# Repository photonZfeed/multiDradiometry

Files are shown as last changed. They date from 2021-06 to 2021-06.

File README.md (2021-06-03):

# multiDradiometry

A device for a multi-dimensional resolving radiometric scanning method.

## Documentaition

The assembly of the device is documented in the [CAD section](./CAD/).

See also the [3D-pdf](./DOCUMENTATION/ND-Radiometry-Scanner/ND-Radiometry-Scanner.pdf) of the complete assembly.

The Python modules are documented in the [Python section](./Python/). See also the fairly detailed docstrings in the code.

## More information
Cite this repository: 

Links to the pulblicatons will be added when available.

## Licensing

<p >
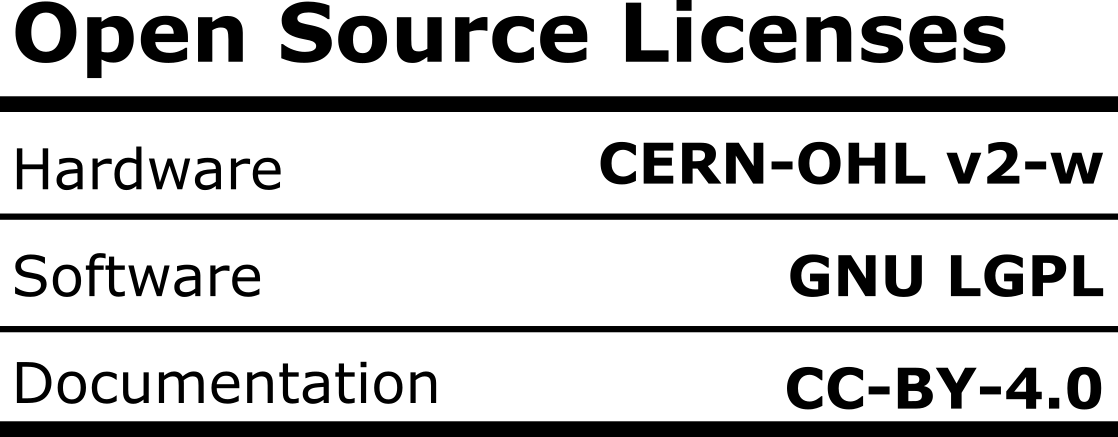
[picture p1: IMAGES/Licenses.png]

</p>

This project is open source. The software is released under the **GNU Lesser General Public Licence** (GNU LGPL). The hardware is released under the **CERN Open Hardware Licence Version 2 - Weakly Reciprocal Licence**.

**Please find the licenses [here](./License.md)**

### Package Licences

multiDradiometry links to or uses the following software, third-party libraries or hardware:

- [itom](https://itom.bitbucket.io/) in version 3.0 under GNU LGPL and ITO LGPL Exception version 1.0.
- [Python](https://python.org) 3 under PYTHON SOFTWARE FOUNDATION (PSF) LICENSE VERSION 2.
- Python-package [NumPy](numpy.org) under BSD compatible license.
- Python-package [feather-format](https://github.com/wesm/feather) under the Apache License, Version 2.0.
- Python-package [pyarrow](https://github.com/apache/arrow/tree/master/python) under the Apache License, Version 2.0.
- Python-package [pandas](https://pandas.pydata.org/) under BSD 3-Clause License.
- Python-package [tinkerforge](https://www.tinkerforge.com/en/doc/Software/API_Bindings_Python.html) under CC0 1.0 Universal License.
- Python-package [matplotlib](https://matplotlib.org) under PSF based, BSD compatible license.
- Python-package [KoradSerial](https://gist.github.com/k-nowicki/5379272) under MIT License.
- Python-package [colour_system](https://scipython.com/blog/converting-a-spectrum-to-a-colour/) by Christian Hill.
- Python-package [yagmail](https://github.com/kootenpv/yagmail) under MIT License.
- Python-package [scipy](https://scipy.org) under PSF based, BSD compatible license.
- Python-package [lmfit](https://lmfit.github.io/lmfit-py/index.html) under BSD-3 License.
- Python-package [sympy](https://github.com/sympy/sympy) under PSF based, BSD compatible License.
- Hardware: [OpenBuilds](https://openbuilds.com/), LLC design work under the CC BY-SA 4.0 License.
- Hardware: [Tinkerforge](https://www.tinkerforge.com) GmbH design work under the CERN Open Hardware License.

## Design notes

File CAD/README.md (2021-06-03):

# Mechanical Setup
The mechanical setup of the scanning device was built to move the spectrometer in x- and y-direction and the light source in z-direction. The scaffold hosting all other mechanical parts is set up with OpenBuilds linear aluminium rails with a length of 1 m. The main scaffold is built up from 12 main beams, namely 4 for every axis. In the following picture, these beams are labelled as main x-beam, main y-beam and main z-beam. Further on, the setup can be subdivided in 4 module types, each presenting one or more corners of the cubic device. To give a general overview, these modules are shown in following pictures as CAD-drawing as they are assembled in the actual device. Assigned colours do not always correspond to real colours but were chosen as visual aid. In addition, parts of the aluminium rails between the modules are cut out. The mechanical structure is self designed, the following parts or assemblies are customly designed, 3D-printed and displayed in dark grey in CAD-figures. They can be found [here](./ND-Radiometry-Scanner).

The modules are named after their position in the coordinate system being scanned by the device. Following this rule, the module which is closest to the origin of the coordinate system is called 000-module.  The individual modules are described in more detail and figure exerts below. 

See also the [3D-pdf](./DOCUMENTATION/ND-Radiometry-Scanner/ND-Radiometry-Scanner.pdf) of the complete assembly.

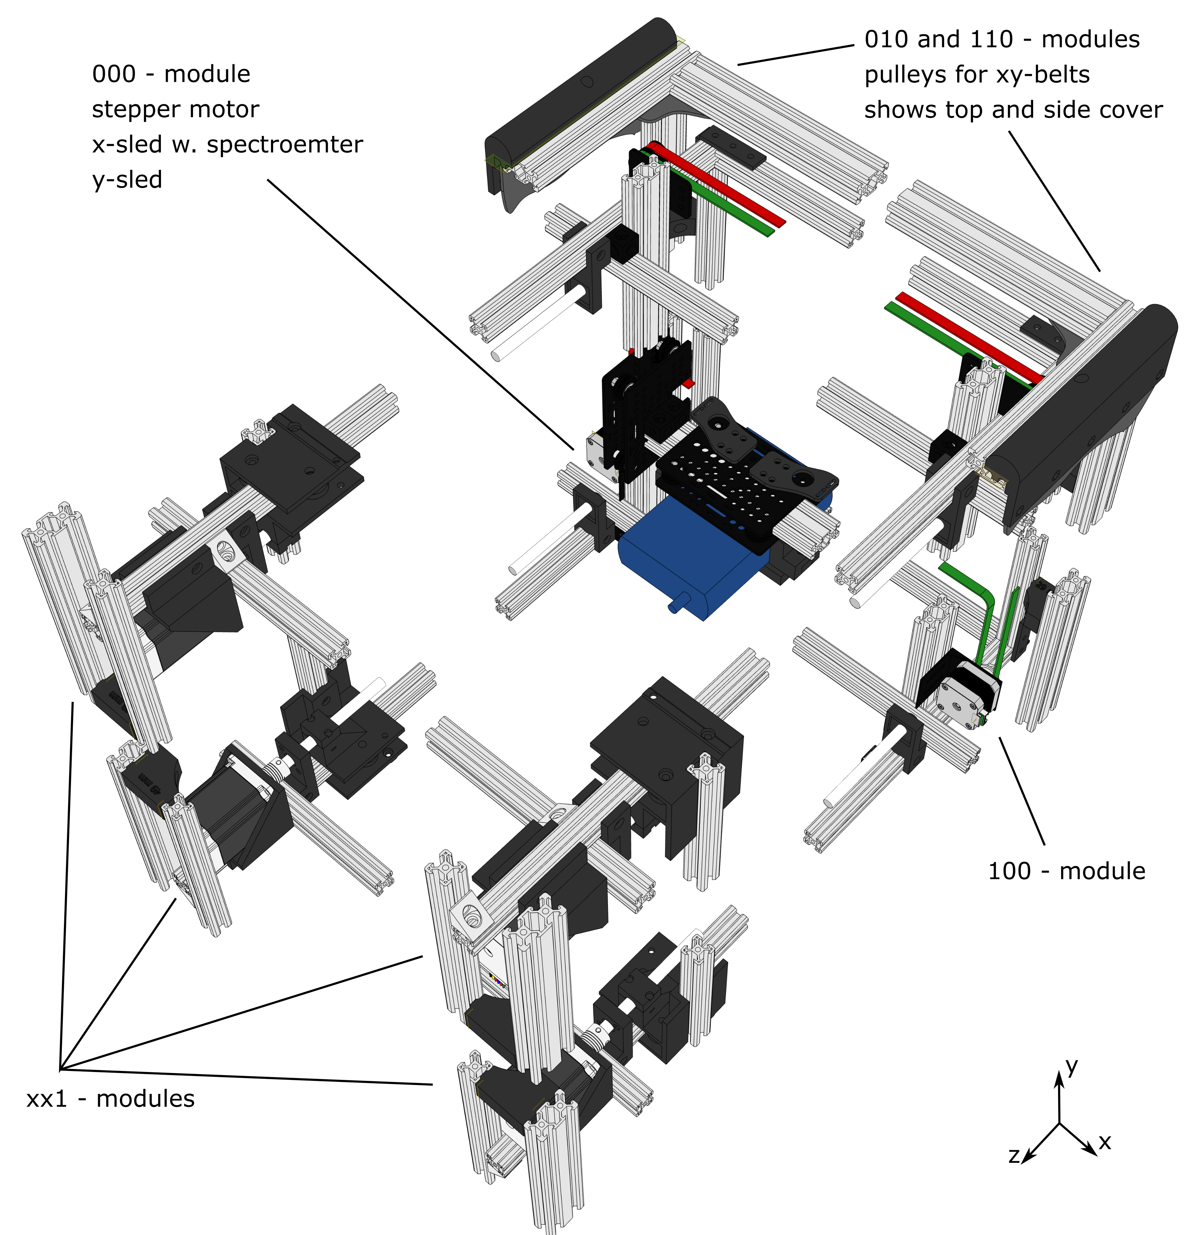
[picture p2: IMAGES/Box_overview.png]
General overview with all building block corners of the scanning device.


### 000-module

The 000-module including the x/y-slid system moving the spectrometer. The Core-XY technique is used to move this slide system. One of two motors needed for this system is visible, connected to the red belt. The spectrometer is mounted on the slide moving in x-direction on an aluminium beam rail. This rail is held by the two slides moving in y-direction on two main y-beams as rails. The general equations describing the movement of the spectrometer in x- and y-directions are:



and



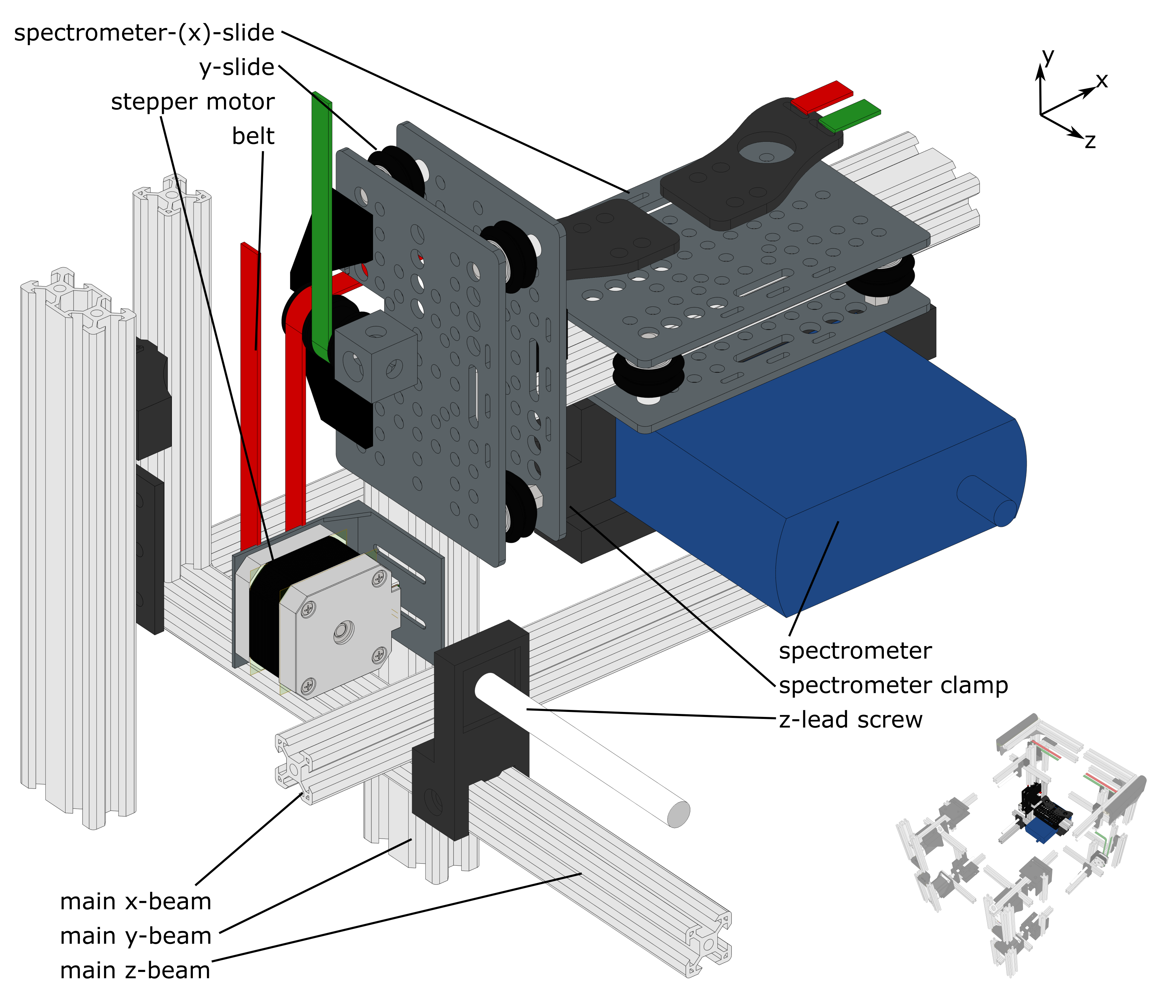
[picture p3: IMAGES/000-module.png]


### 100-module
The second motor moving the spectrometer is visible in the following figure, connected to the green belt. Here the y-slide is omitted for a better display of the main x, y and z-beam. The latter also hosts the z-lead screw, which is driving the z-slide. The belts for the x/y-slits are deflected by pulleys at the 010 and 110 position. 

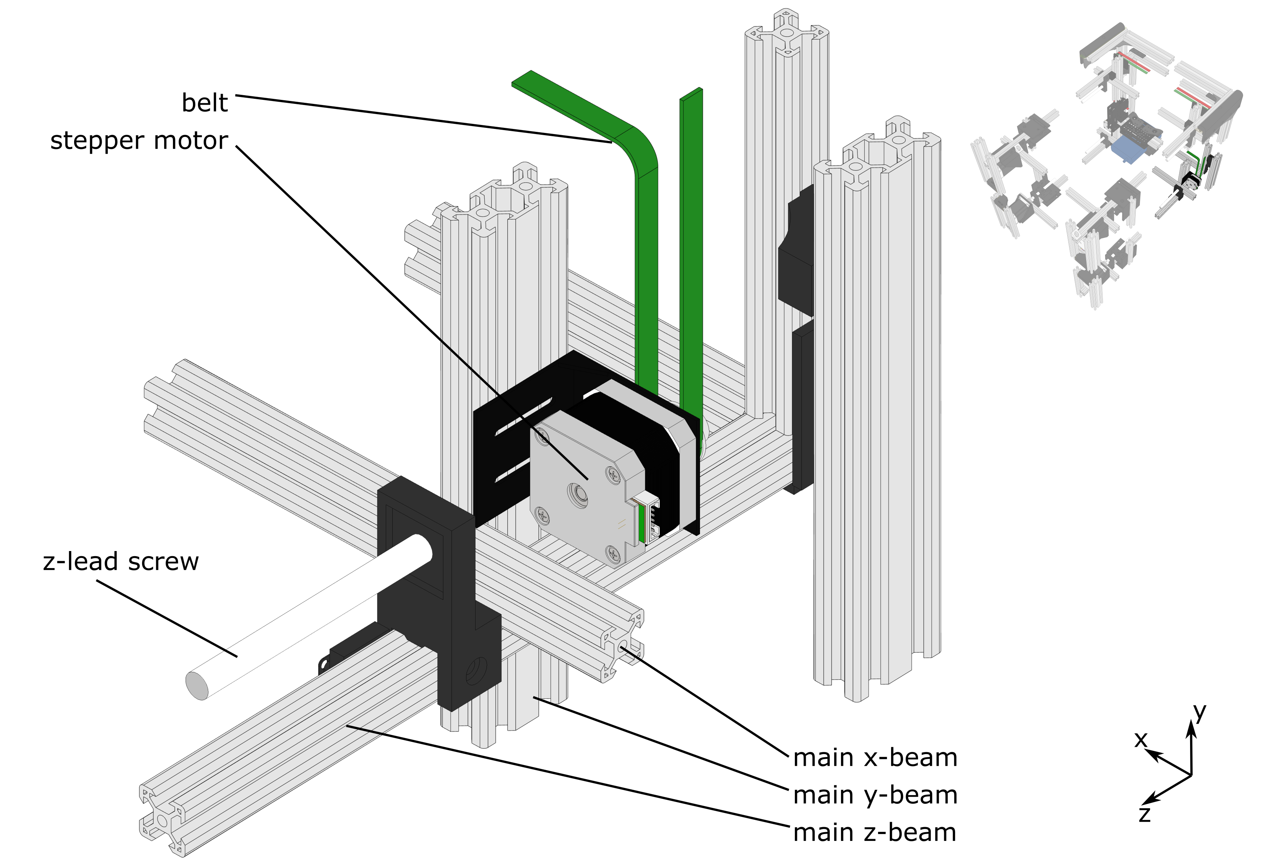
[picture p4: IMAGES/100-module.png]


### 010- and 101-module
To protect the scanning device from interfering light, the device can be covered with black polypropylene panels. The panel on the top side is mounted on a frame of aluminium beams and is screwed to the main scaffold. On this top cover frame, the side cover panels can be mounted by hanging them on the aluminium beams of the top cover. The hanging panels are then fixed at the cover gantry, which consists of aluminium rails connected with spacers to the main scaffold. The scaffold and spacers are shown in all CAD-figures, however, they are best visible in the following figure. This figure also shows one of 4 modules driving the z-slide assembly. This assembly consists of four slides running in all main z-beams as rails. The slides are all driven by a lead-screw and a stepper motor, moving only at the same time. The z-slides can be connected by aluminium beams to establish a moving scaffold for hosting the light source.

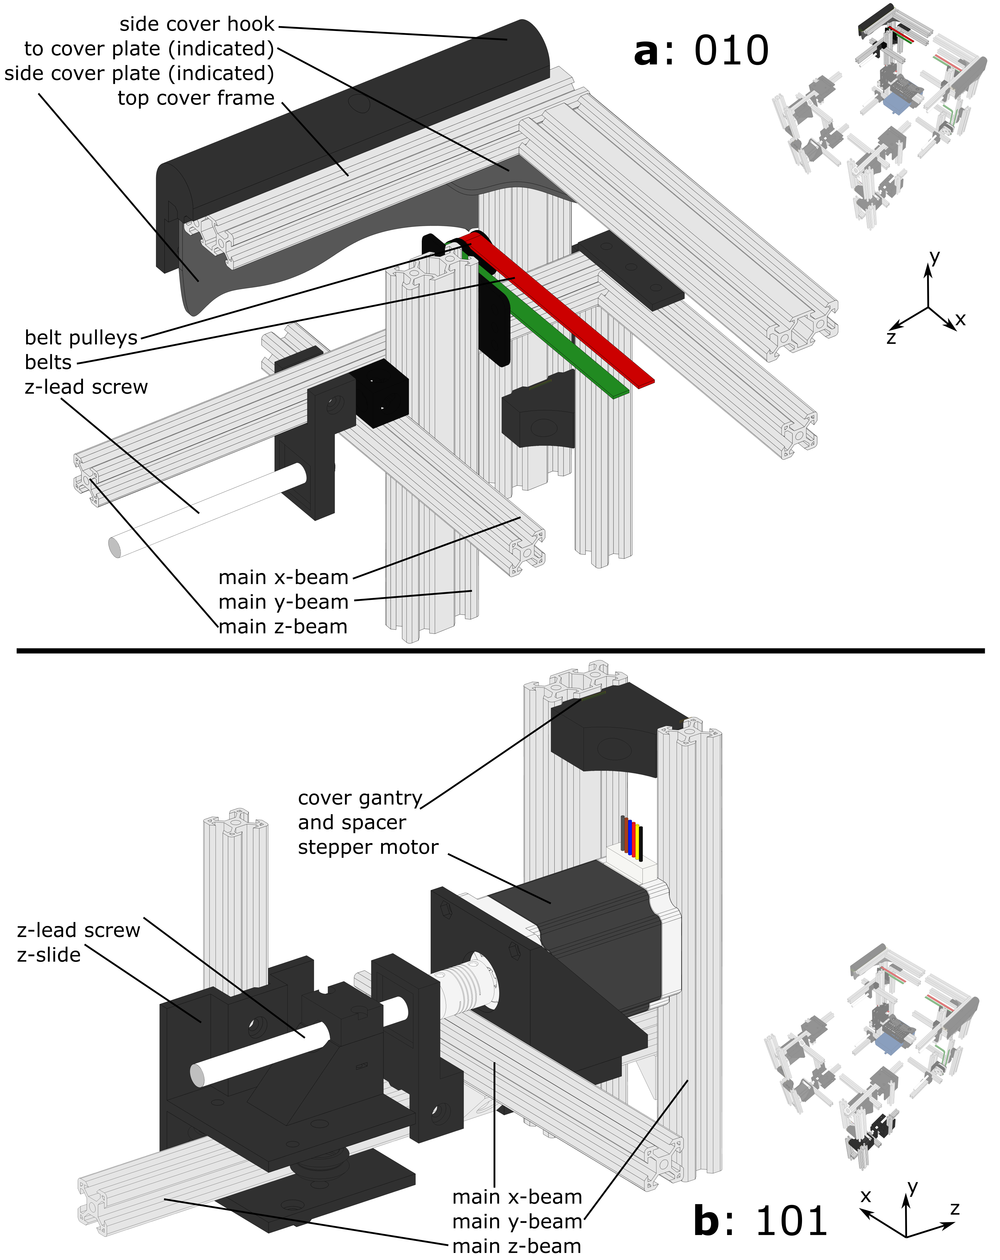
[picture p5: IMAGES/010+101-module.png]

## Tips to setup a new device

Start setting up the x/y frame and include the slides. Then you can install and test the electronixs for the x/y movement without too much space demands. Then yo can expand to the full frame and integrate the z-movement parts.

# Electric setup
The following figure shows a schematic setup of the used tinkerforge bricks to control the device. The master brick is connected to the PC running the controlling software. All bricks are stacked on top of each other, all bricklets are connected via cables. Each stepper brick is controlling one stepper motor for the x- and y-movement. Another stepper brick is controlling all stepper motors for the z-movement. One IO-16-bricklet is used to watch the end-stop triggers. A 24 V wall plug power supply is powering the stepper bricks as well as the cooling fan of the tinkerforge assembly. The used spectrometer and the power supply are connected directly to the PC via USB.
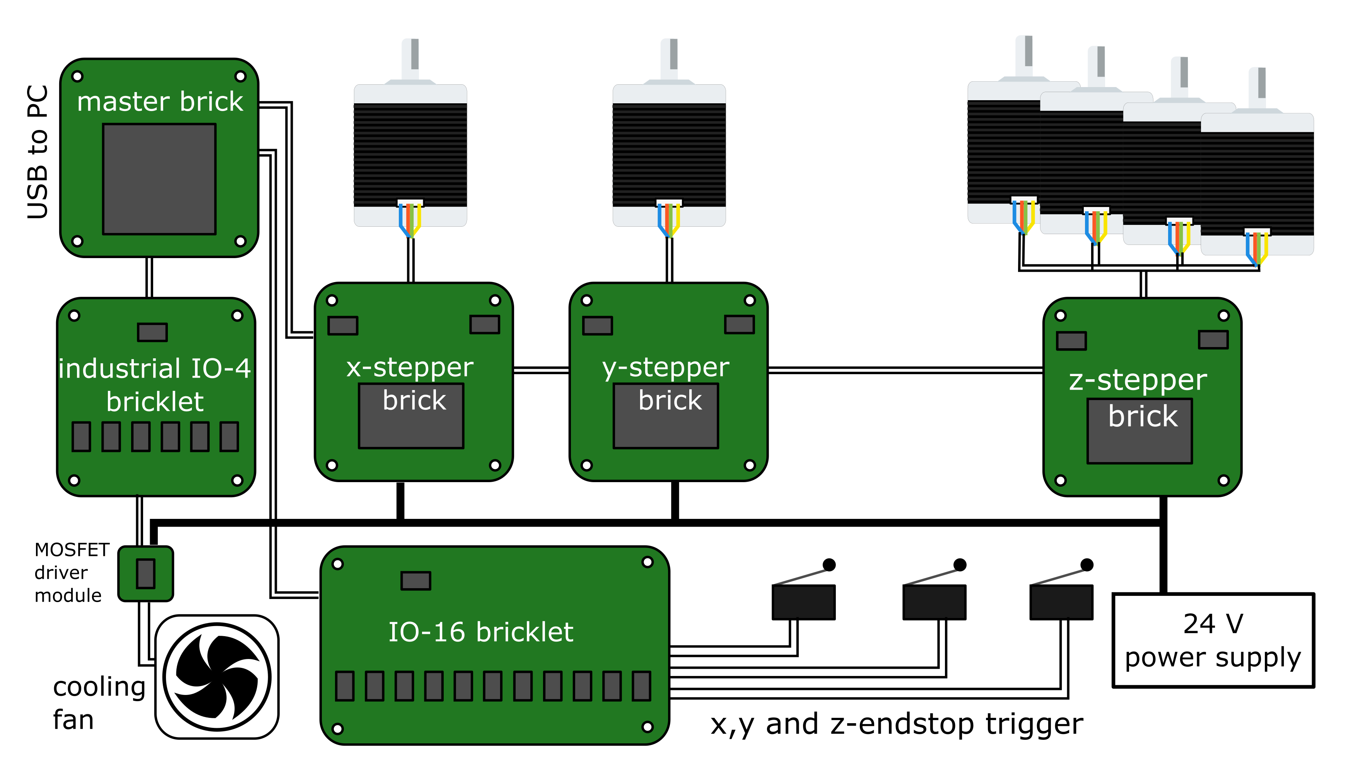
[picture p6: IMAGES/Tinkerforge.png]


# List of Parts

|  | Rails |
| --- | --- |
|12	|1000x20x20 V-slot rail|
|4	|860x20x20 V-slot rail|
|2	|913x20x20 V-slot rail|
|1	|975x20x20 V-slot rail|
|6	|1000x40x20 V-slot rail|
|2	|960x40x20 V-slot rail|
|1	|810.4x40x20 V-slot rail|

|	|OpenBulids Parts|
| --- | --- |
|2	 |idler pulley plate|
|2	 |NEMA 17 90deg mount plate|
|8	 |straight bracket|
|18	 |Three way cube|
|12	|6\,mm spacer|
|16	|asymmetric spacer|
|2	|Gantry Plate - universal|
|4	|Gantry Plate - universal (cut to fit belts)|
|8	|smooth idler pulley assembly|
|24	|V-Slot wheel assembly|

| | Screws and Nuts|
| --- | --- |
|32	|M3 nut|
|16	|M3 square nut|
|32	|M3x10 ISO 7380|
|8	|M3x25 ISO 7380|
|12	|M3x8 ISO 7380|
|16	|M4 nut|
|16	|M4x10|
|4	|M5 1mm spacer|
|82	|M5 nut|
|154	|M5 tee nut|
|165	|M5 washers|
|6	|M5x20 ISO 7380|
|16	|M5x35 ISO 7380|
|12	|M5x40 ISO 7380|
|8	|M5x60 ISO 4762|
|65	|M5x8 ISO 10642|
|137	|M5x8 ISO 7380|
	
| | Moving and Other|
| --- | --- |
|2	 |16 teeth HTD 3M  9mm belt pulley|
|8	 |19x10x5 ball bearing|
|4	 |6mm/10mm coupling|
|4	 |leadscrew Tr.10x3x1000|
|4	 |Tr.10 x 3 hex nut length15mm width17mm|
|5	|3x1000x1000 black PP |
|13|\m	HTD 3M  9mm belt|

| | Printed Parts|
| --- | --- |
|8	 |cover gantry spacer|
|4	 |leadscrew end holder|
|4	 |leadscrew support|
|1	 |spectrometer clamp |
|4	 |z-motor mount|
|4	 |z-slide|
|2	|belt attachment|
|3	|limit switch mount|
|2	|pulley support|
|8	|side cover kook|
	
| | Electronic Parts|
| --- | --- |
|2	 |NEMA 17 stepper motor|
|4	 |NEMA 23 motor|
|1	|24V power supply|
|6 m|	end switch cable|
|1	|Industrial IO-4 bricklet|
|1	|IO-16 bricklet|
|3	|limit switch|
|1	|master brick|
|1	|micro usb cable|
|1	|mosfet driver module|
|3	|stepper brick|
|15 m|	stepper motor cable|
|2	|tinker forge cable|

# Capillary Reactor Models

The CAD-models of the reactors used in the linked publication can be found [here](./Reactors/).

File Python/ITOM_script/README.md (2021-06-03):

# radiometric_measurement

---

The module` radiometric_measurement `contains the class `ScanSurface`, which can be run in an ITOM environment to perform measurements with a radiometric scanning device developed at the Institute of Chemical Engineering, Ulm University.
    
The class ScanSurface controlling the measurement device is connected to the spectrometer, the power supply and the tinkerforge bricks, which control the stepper motors and end-stop switches. Must be run in an ITOM python environment.

## Usage
The following cole block shows an example of a script initializing an instance of the class `ScanSurface` class and starting a measurement. This script must be executed in ITOM. In line 3, the class instance `sc` gets initialized with the parameters described in the following section. After connecting to the hardware in line 8, the measurement is started in line 10 after a waiting time to leave the lab (line 9).

	from Skripts.radiometric_measurement import ScanSurface
	import time
	
	sc = ScanSurface(reactor='example_name', comment='example_comment', measurements=5, power_supply=True, current=0.5,
	                 slicelist=[10.8, 11.19, 11.58, 11.97, 12.36], 
	                 int_time_list=[0.142, 0.152, 0.163, 0.174, 0.185]
	                 )  # initialize an instance of the ScanSurface class
	sc.connect()
	time.sleep(2)  # an apropirate time to leave the lab
	sc.start_measurement()  # start the measurement

### Attributes constructed by \_\_init\_\_:

**reactor** ***(str):*** The name of the experiment, will be used for output folder and files.

**comment** ***(str):*** A comment for additional information, written to the logfile.

**measurements** ***(int):*** The size of measurements of a quadratic canvas in x/y-direction. The points are evenly spaced by 3.9 mm. The maximum total size is 153 (59.67 cm).

**power\_supply** ***(bool):*** If `True`, the script controlls the power supply with the given parameters for voltage and current. If `False`, a dark spectrum for the chosen integration time must be provided in the format "dark_'integration time'\_av'averages'.csv", whereas 'integration time' and 'averages' must be replaced with the respective numbers. The provided python script *darkspec.py* can help with that.

**voltage** ***(number, optional, default = 5.0):*** The voltage set for the power supply in Volt.

**current** ***(number, optional, default = 0.7):*** The current set for the power supply in Ampere.

**slicelist** ***(list):*** Sets up a list for all z-positions, in cm, to be measured: `[pos1, pos2, pos3...]`.

**int\_time\_list** ***(list):*** Sets up a list of the integration time for all z-positions, in seconds: `[time1, time2, time3...]`. Must be of the same length as parameter slicelist.

**averages** ***(int, optional, default = 2):*** The number of spectrometer measurements which result in one averaged measurement sent to python. A new transfer curve is needed for different average settings.

**x_start** ***(number, optional, default = 0.0):*** The x-position of the first measured pixel in cm.

**y_start** ***(number, optional, default = 0.0):*** The y-position of the first measured pixel in cm.

**log\_output** ***(boolean, optional, defalut = True):*** Saves a logfile, this is mandatory for further evaluation.

**linspace** ***(tuple, optional, default = False):*** Sets up a slicelist in the manner of the numpy linspace function *(start, stop, num)*. Linspace definitions can't be defined together with a list definition (slicelist or int\_time\_list)!

**int\_time\_linspace** ***(tuple, optional, default = False):*** Sets up an integration time list in the manner of the numpy linspace function *(start, stop, num)*. Must be used together with parameter linspace.

**sendmail** ***(bool, default is False):*** If `True`, the script will send a status mail after the 50th measurement of a respective z-slice. Attributes should be changed in the code.

### Attributes for status and debugging:

**is\_homed** ***(bool):*** Indicates overall homing status.

**bool\_home\_x** ***(bool):*** Indicates x homing status.

**bool\_home\_y** ***(bool):*** Indicates y homing status.

**z\_is\_homed** ***(bool):*** Indicates z homing status.

**status** ***(str):*** Indicated status `'idle'`, `'measuring'` or `'homing'`.

**path** ***(str):*** The filepath for result export. Normally consisting of '02Results/' the time as "%y%m%d_%H%M%S" and the string of the attribute reactor.

#### Attributes for the status mail function:

If sendmail is `True`, the script will send a status mail after the 50th measurement of a respective z-slice. Attributes should be changed in the code ([line 346](./Skripts/radiometric_measurement.py#L347-348)):

**yag** = yagmail.SMTP('fill your email here', 'fill your password here or use the keychain functionality of yagmail')

**mailto** ***(str):*** The receivers e-mail address.

**mailsubj** ***(str):*** Automatically generated subject.

**mailcont** ***(str):*** Automatically generated content.

**approx\_string** ***(str):*** Automatically generated string of the approximate ending time of the scan.

#### Attributes for Tinkerforge and Steppermotor setup:

For setting up a new machine, or if tinkerforge hardware is replaced, the respetive UIDs must be typed in the code ([line 300](./Skripts/radiometric_measurement.py#L300-304)):
	
**UIDSTEP1** ***(str):*** UID of Stepper Brick 1
	
**UIDSTEP2** ***(str):*** UID of Stepper Brick 2 Since a core xy-setup is used, there is no such a x or y stepper.
	
**UIDSTEP3** ***(str):*** UID of Stepper Brick 3 (z-direction).
	
**UIDIO** ***(str):*** UID of IO-16 Bricklet.
	
**UIDIDO4** ***(str):*** UID of IO-4 Bricklet.

**Optional tinkerforge attributes:**

**HOST** ***(str):*** "localhost"
	
**PORT** ***(int):*** 4223
	
**max\_vel** ***(int):*** Velocity of stepper 1 and 2.
	
**ramping** ***(int):*** Ramping of stepper 1 und 2.
	
**z\_max\_vel** ***(int):*** Velocity of z-steppers.
	
**z\_ramping** ***(int):*** Ramping of z-steppers.

#### Methods:

Please refer to the detailed docstrings insde the module's [code](./Skripts/radiometric_measurement.py).

- connect()

- start\_measurement()

- disconnect()

##### Debugging methods for idle mode: 
(idle mode = connected and homed, no measurement running, `mode=='idle'`)

- get\_position()

- get\_z\_position()

- goto\_position(position)

- tune\_inttime()

- manual\_homing()

- reset\_queue()

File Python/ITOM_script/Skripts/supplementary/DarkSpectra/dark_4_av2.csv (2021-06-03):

3.990000000000000000e+03
6.418500000000000000e+03
4.458000000000000000e+03
5.919500000000000000e+03
4.909000000000000000e+03
6.655500000000000000e+03
6.343000000000000000e+03
4.787000000000000000e+03
3.453500000000000000e+03
6.850000000000000000e+03
4.748500000000000000e+03
4.992500000000000000e+03
3.585000000000000000e+03
3.245500000000000000e+03
6.811500000000000000e+03
3.690000000000000000e+03
3.497000000000000000e+03
4.898500000000000000e+03
6.650500000000000000e+03
4.362500000000000000e+03
4.449500000000000000e+03
6.489500000000000000e+03
5.195000000000000000e+03
4.325000000000000000e+03
4.003000000000000000e+03
3.364500000000000000e+03
3.430500000000000000e+03
5.001500000000000000e+03
6.186500000000000000e+03
4.387000000000000000e+03
6.308000000000000000e+03
5.852000000000000000e+03
2.372500000000000000e+03
2.795000000000000000e+03
4.074000000000000000e+03
3.335000000000000000e+03
3.668000000000000000e+03
7.014000000000000000e+03
5.184500000000000000e+03
2.922000000000000000e+03
4.767500000000000000e+03
5.801500000000000000e+03
2.923000000000000000e+03
3.774000000000000000e+03
3.041500000000000000e+03
4.266500000000000000e+03
3.547500000000000000e+03
3.729500000000000000e+03
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

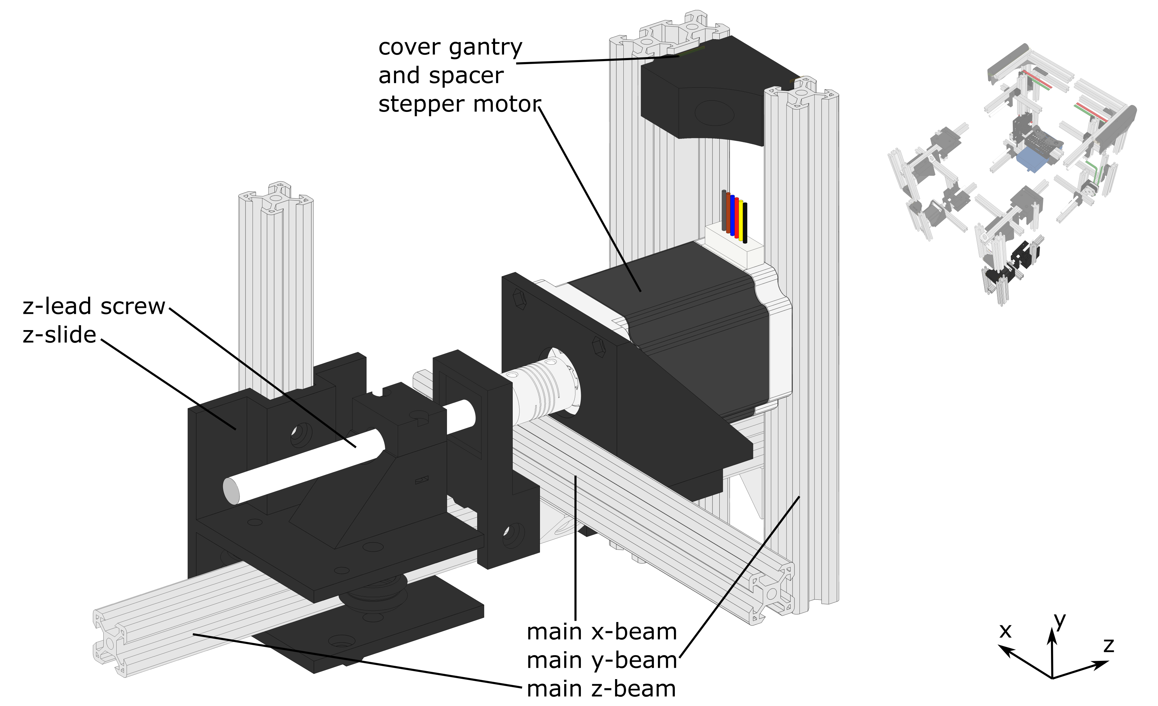
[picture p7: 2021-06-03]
IMAGES/101-module.png

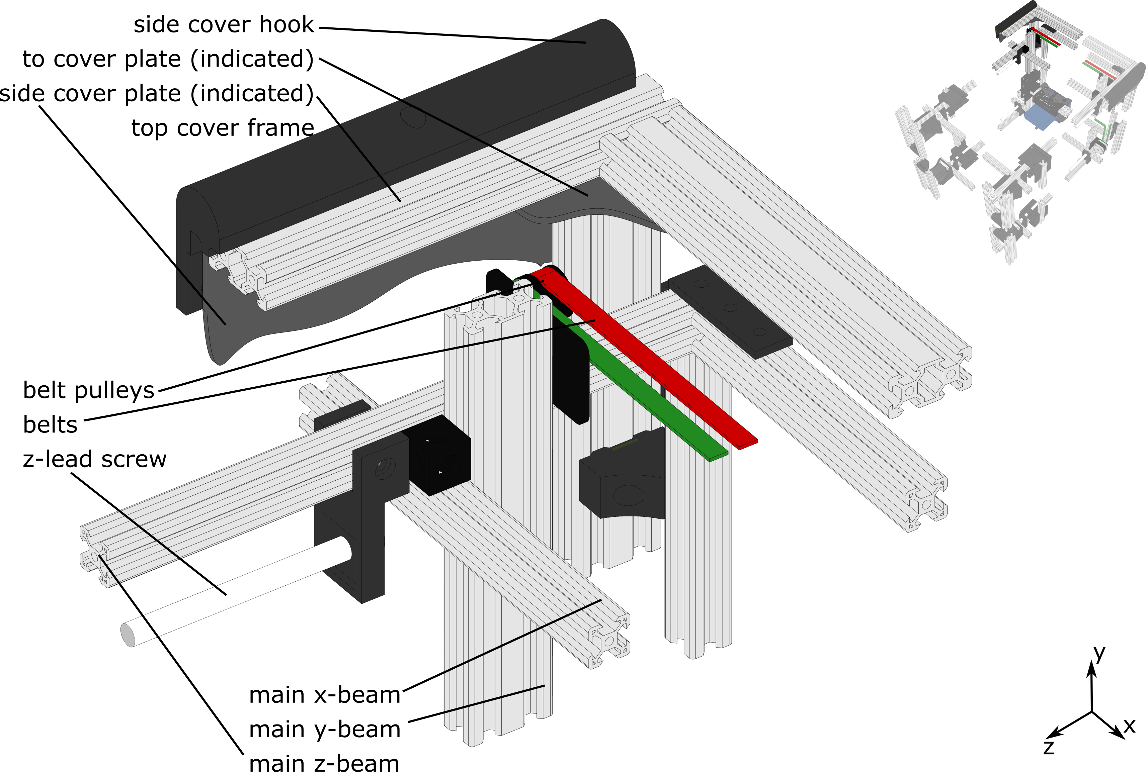
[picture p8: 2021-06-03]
IMAGES/010-module.png

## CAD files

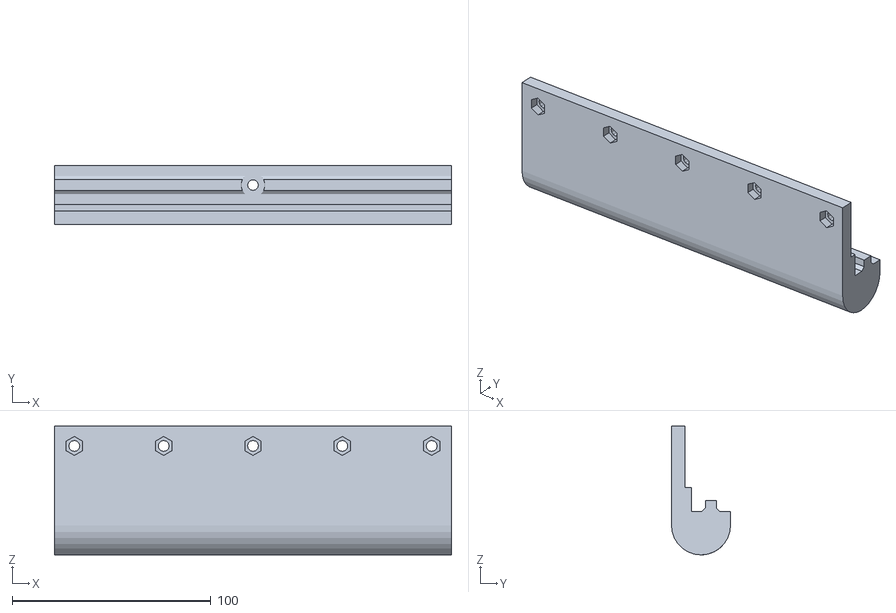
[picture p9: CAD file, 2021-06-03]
CAD/ND-Radiometry-Scanner/side_cover_hook.stl
200.0 x 29.8 x 64.9

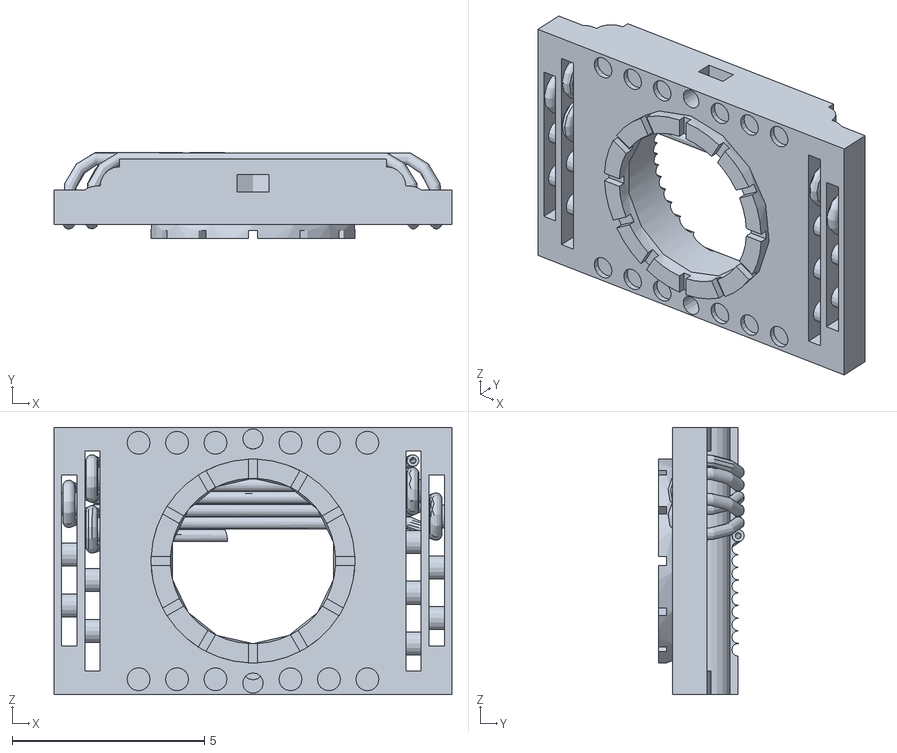
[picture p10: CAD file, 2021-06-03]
CAD/Reactors/SR_openend_with_caps.stl
10.4 x 2.22 x 6.95

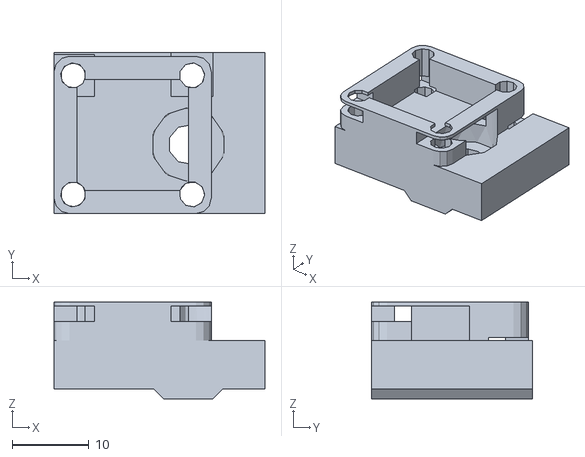
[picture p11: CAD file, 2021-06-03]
CAD/ND-Radiometry-Scanner/z_endstop_holder.stl
27.5 x 21.0 x 12.6

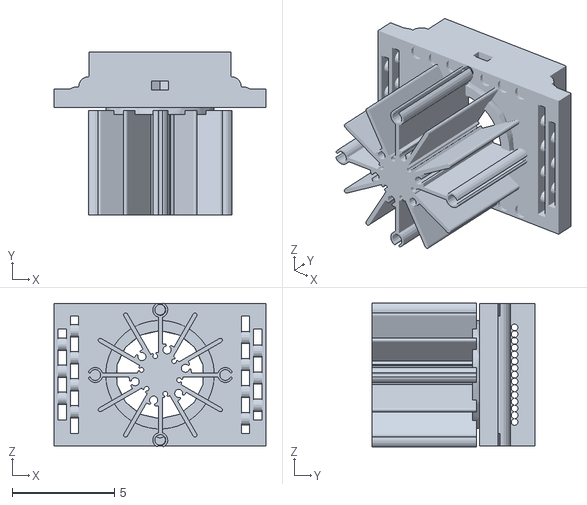
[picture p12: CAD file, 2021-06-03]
CAD/Reactors/SR.stl
10.4 x 7.97 x 7.01

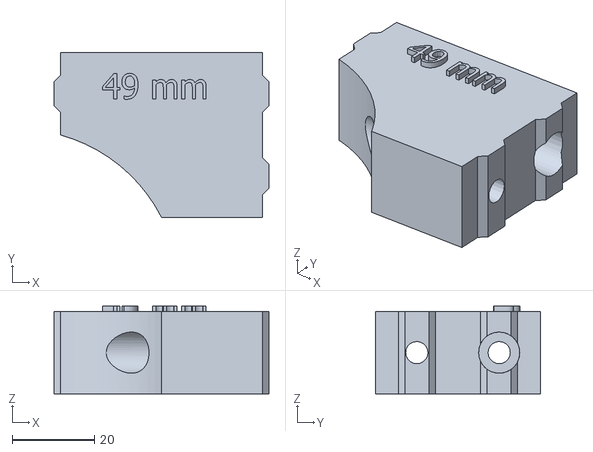
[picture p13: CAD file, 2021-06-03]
CAD/ND-Radiometry-Scanner/cover_gantry_spacer_4_9.stl
52.2 x 40.0 x 21.3

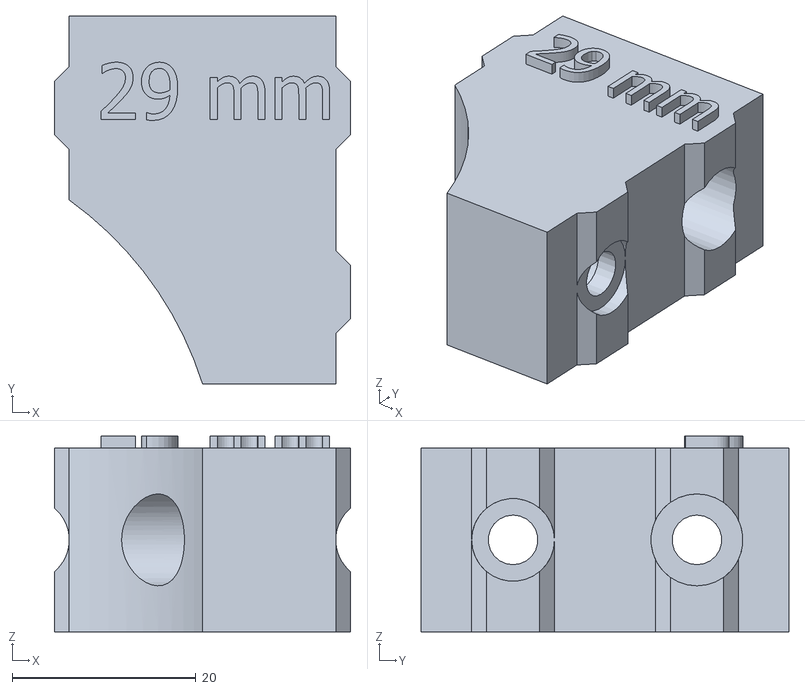
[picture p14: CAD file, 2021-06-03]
CAD/ND-Radiometry-Scanner/cover_gantry_spacer_2_9.stl
32.2 x 40.0 x 21.3

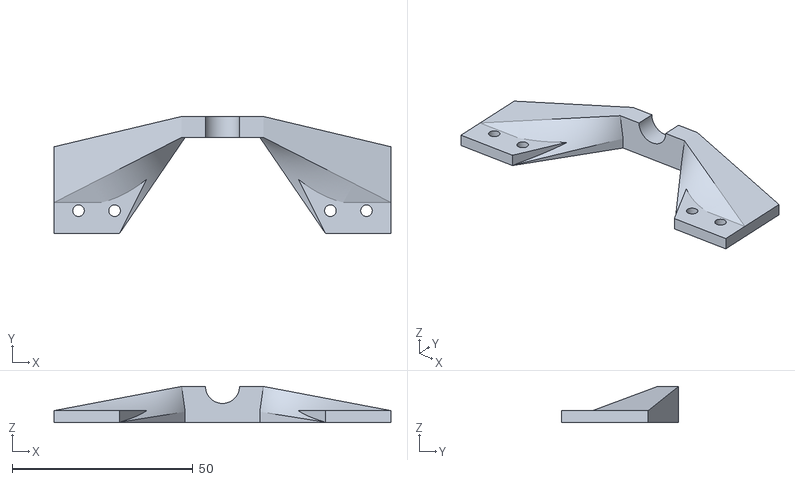
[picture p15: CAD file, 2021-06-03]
CAD/ND-Radiometry-Scanner/y_slide_pulley_support.stl
93.3 x 32.4 x 10.0

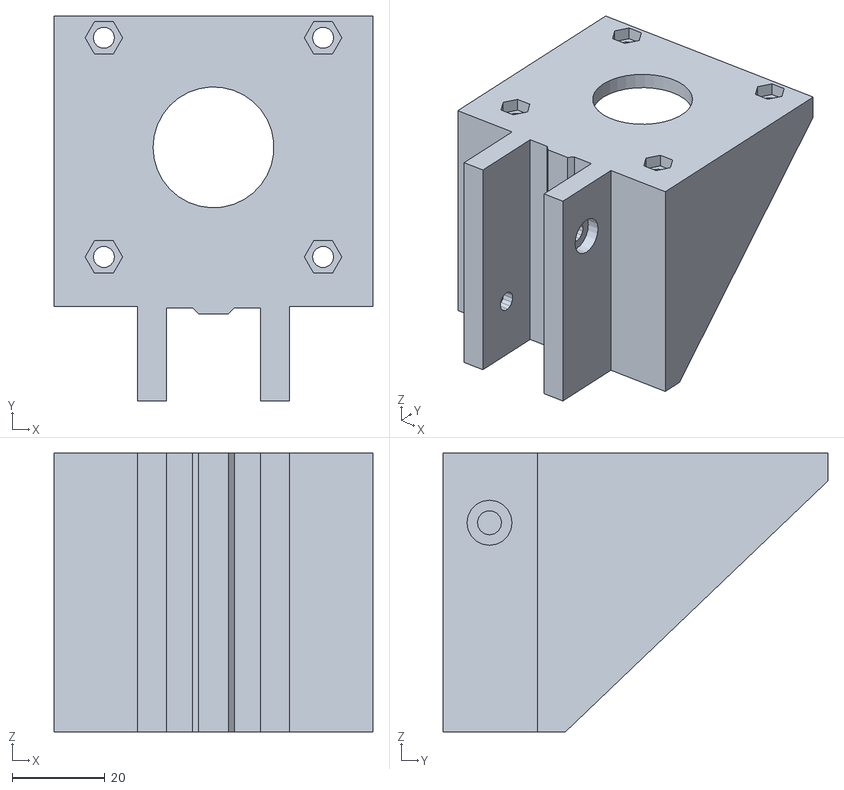
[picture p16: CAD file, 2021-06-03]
CAD/ND-Radiometry-Scanner/z-motor_holder.stl
68.5 x 82.8 x 60.0

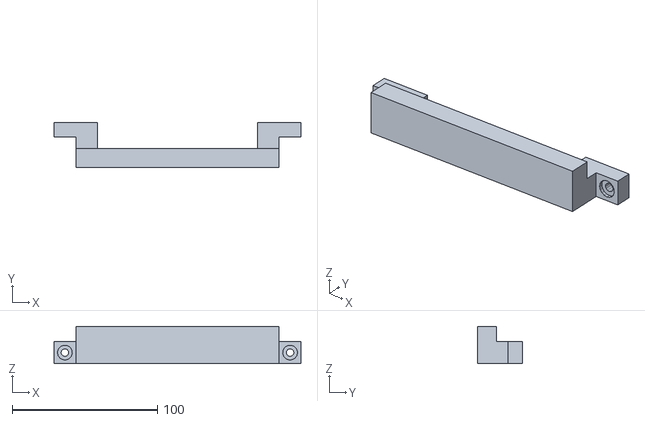
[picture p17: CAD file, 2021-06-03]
CAD/ND-Radiometry-Scanner/spectrometer_clamp_part1.stl
170.0 x 31.0 x 25.5

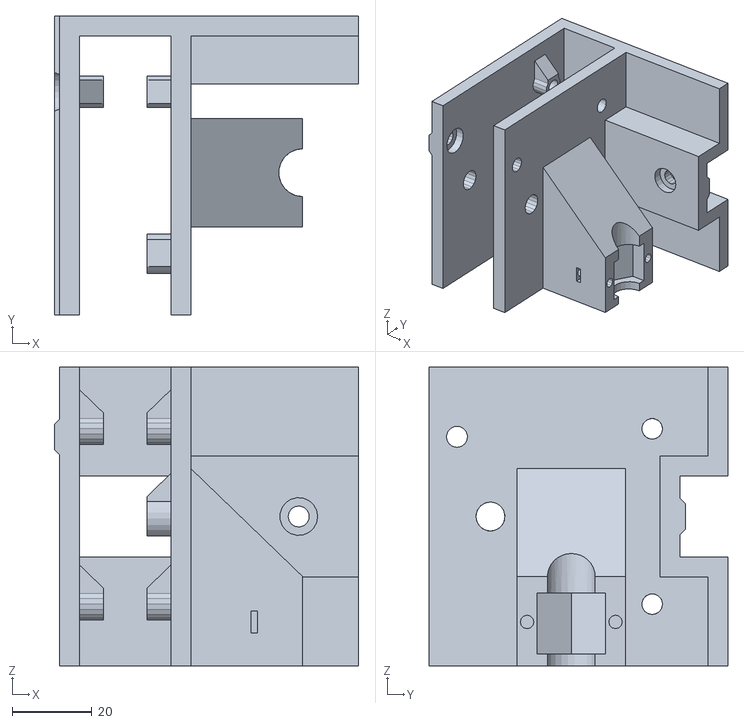
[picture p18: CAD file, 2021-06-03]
CAD/ND-Radiometry-Scanner/z-sled_011_and_101.stl
76.3 x 75.0 x 75.0

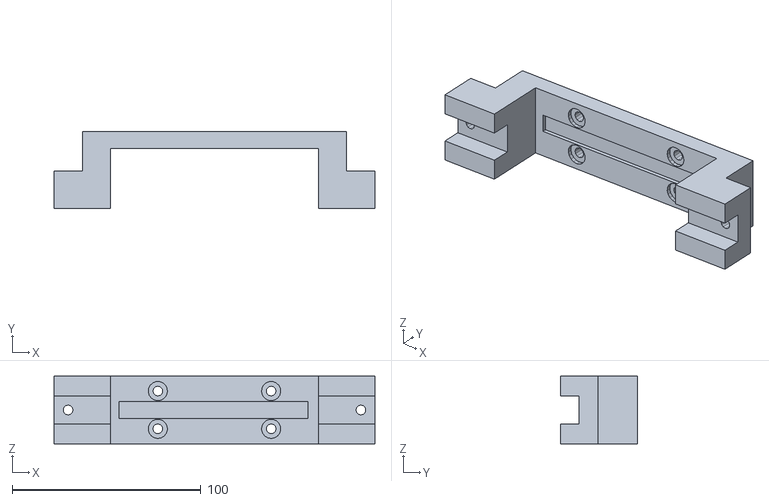
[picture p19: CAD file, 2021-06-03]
CAD/ND-Radiometry-Scanner/spectrometer_clamp_part2.stl
170.0 x 41.0 x 36.0

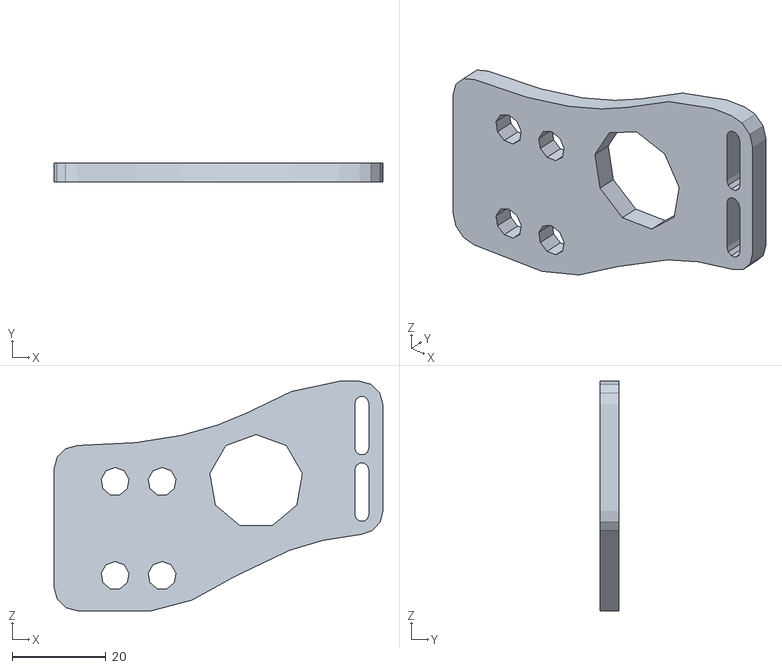
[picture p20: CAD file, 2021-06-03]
CAD/ND-Radiometry-Scanner/x-slide_belt_attachment.stl
70.0 x 4.00 x 48.9

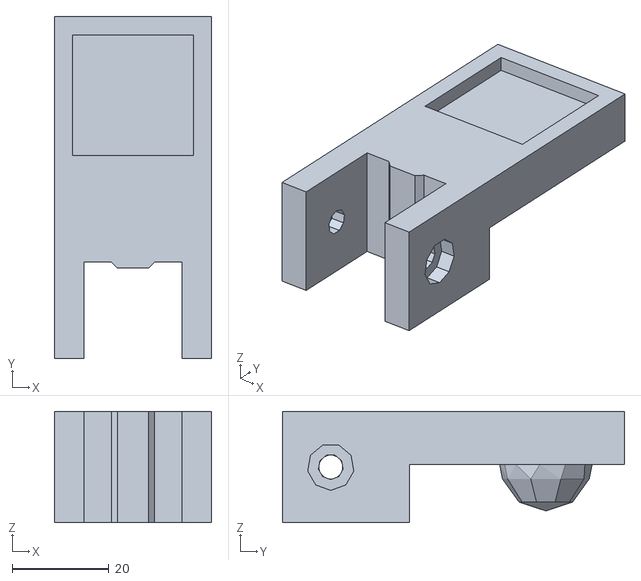
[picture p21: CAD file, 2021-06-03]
CAD/ND-Radiometry-Scanner/leadscrew_holder_end.stl
32.6 x 70.9 x 23.0

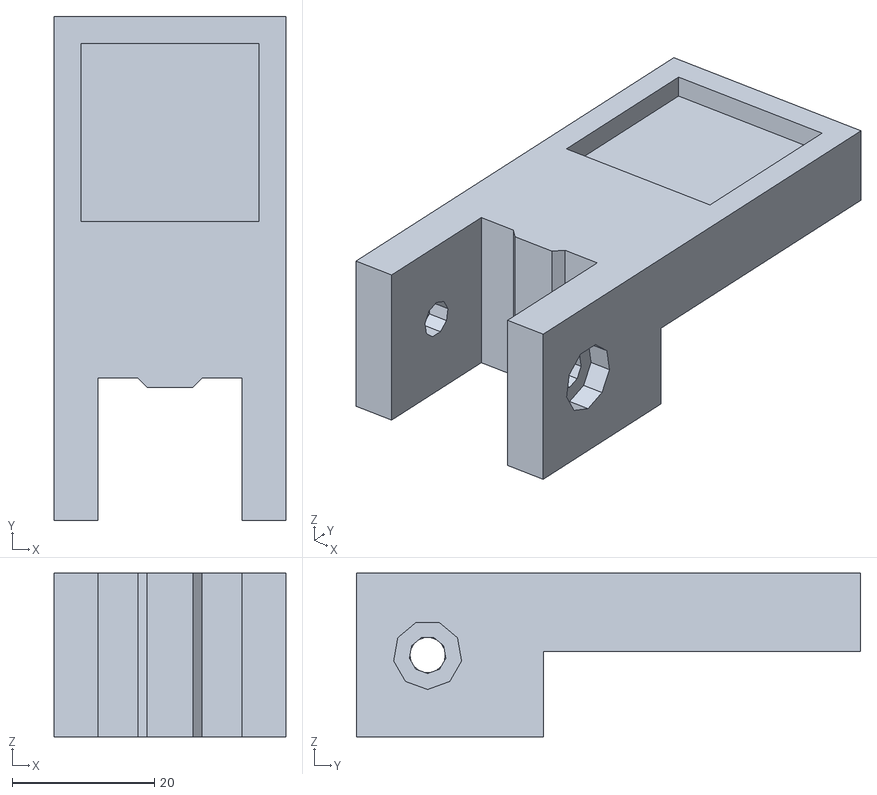
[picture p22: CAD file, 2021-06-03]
CAD/ND-Radiometry-Scanner/leadscrew_support.stl
32.6 x 70.9 x 23.0

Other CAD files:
CAD/ND-Radiometry-Scanner/z-sled_001_and_111.stl
CAD/ND-Radiometry-Scanner/leadscrew_support_cap.stl
CAD/ND-Radiometry-Scanner/z-sled_nut_cover.stl

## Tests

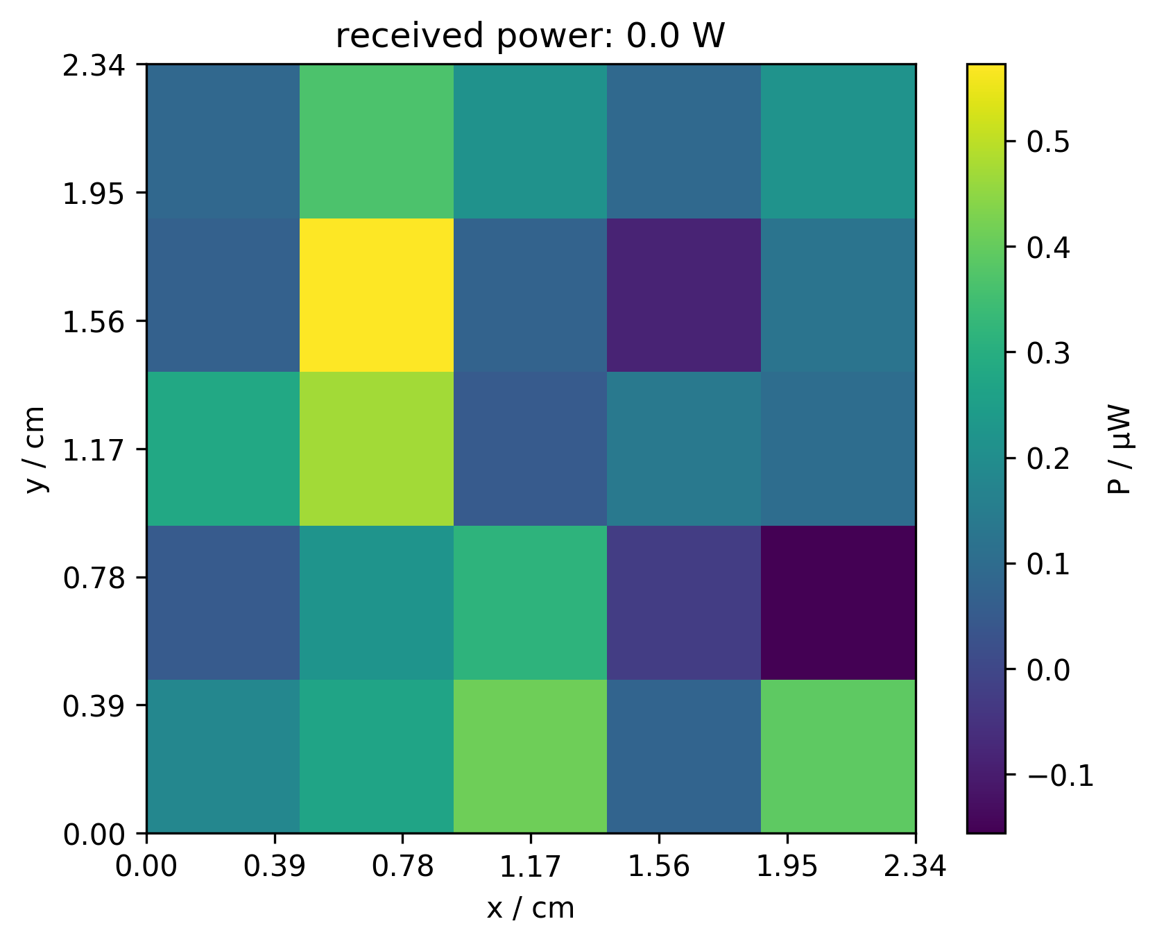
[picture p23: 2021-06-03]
Python/ITOM_script/02Results/210430_115323_example_name/12.36_mm/Colormapexample_name.png

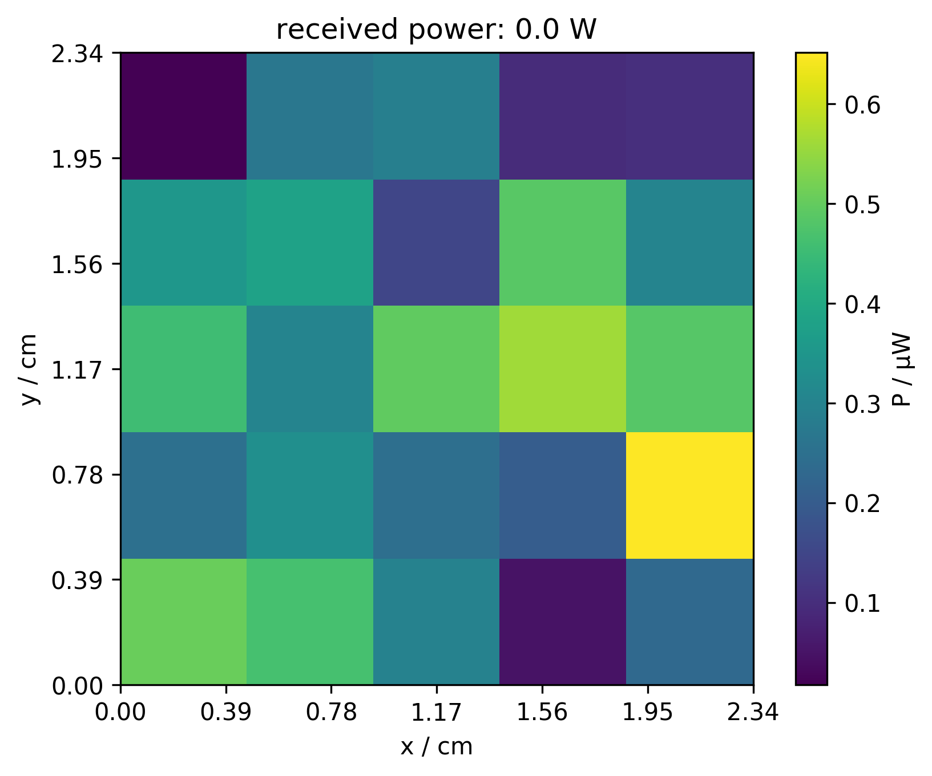
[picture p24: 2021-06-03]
Python/ITOM_script/02Results/210430_115323_example_name/11.97_mm/Colormapexample_name.png

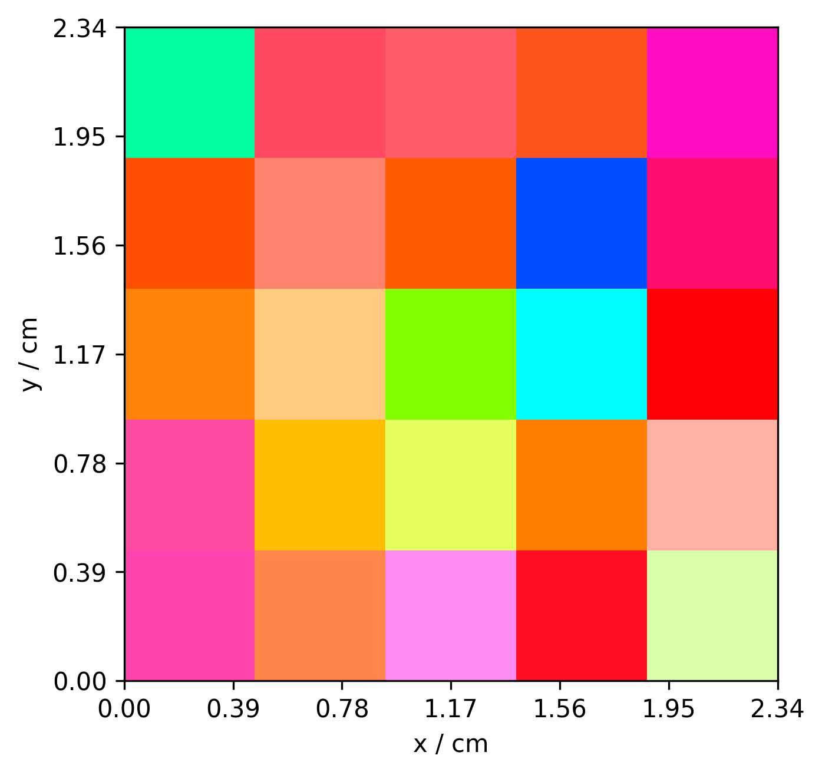
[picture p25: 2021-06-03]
Python/ITOM_script/02Results/210430_115323_example_name/12.36_mm/Farbbildexample_name.png

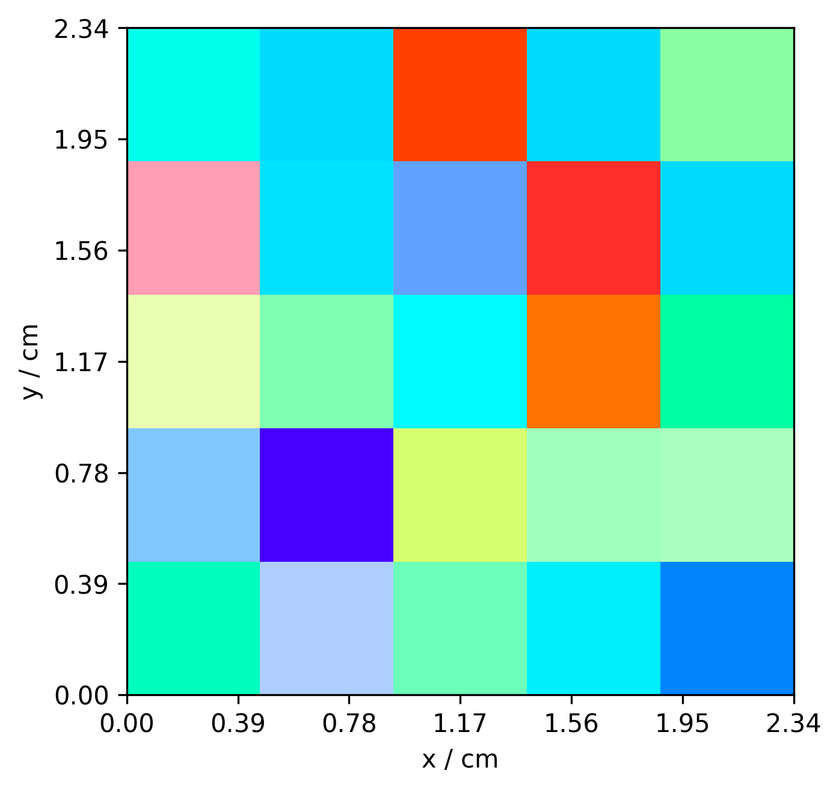
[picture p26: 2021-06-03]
Python/ITOM_script/02Results/210430_115323_example_name/11.19_mm/Farbbildexample_name.png

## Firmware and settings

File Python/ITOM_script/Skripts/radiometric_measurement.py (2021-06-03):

# -*- coding: utf-8 -*-
# =============================================================================
# Created By  : Maximilian Sender
# Copyright   : Copyright 2021, Institute of Chemical Engineering, Prof. Dr. Dirk Ziegenbalg, Ulm University'
# License     : GNU LGPL
# =============================================================================
"""The module radiometric_measurement contains the class ScanSurface, which can be run in an ITOM environment to perform
measurements with a radiometric scanning device developed at the Institute of Chemical Engineering, University Ulm

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

class ScanSurface:
    """
    The class ScanSurface controlling the measurement device is connected to the Spectrometer, the power supply and the
    tinkerforge bricks, which control the stepper motors and end-stop switches. Must be run in an ITOM python
    environment.

    For detailed description see also the documentation of __init__.

        -------------------
        Attributes constructed by __init___:

            reactor (str):
                Name of the reactor (experiment).
            comment (str):
                A comment written to the logfile.
            sendmail (bool):
                Switches on a status update via mail.
            measurements (int):
                Size of the measurement.
            power_supply (bool):
                Switch for power supply (PS) use.
            averages (int):
                Number of averages of spectrometer acquisition.
            x_start (number):
                Scan start in x direction.
            y_start (number):
                Scan start in y direction.
            voltage (number):
                Voltage of PS.
            current (number):
                Current of PS.
            log_output (bool):
                Switch of log file output.
            slicelist:
                List defining the scans z-position.
            int_time_list:
                List defining the integration time of the spectrometer at the respective z-position.
            sendmail (bool, default is False):
                If True, the script will send a status mail after the 50th measurement of a respective z-slice.
                Attributes should be changed in the code.

        -------------------
        Attributes for status and debugging:
            is_homed (bool):
                Indicates over all homing status.
            bool_home_x (bool):
                Indicates x homing status.
            bool_home_y (bool):
                Indicates y homing status.
            z_is_homed (bool):
                Indicates z homing status.
            status (str):
                Indicated status 'idle', 'measuring' or 'homing'.
            path (str):
                The filepath for result export. Normally consisting of '02Results/' the time as "%y%m%d_%H%M%S" and the
                string of the attribute reactor.

        -------------------
        Attributes for the status mail function:
            yag = yagmail.SMTP('fill your email here', 'fill your password here or use the keychain functionality of yagmail')
            mailto (str):
                The receivers e-mail address.
            mailsubj (str):
                Automatically generated subject.
            mailcont (str):
                Automatically generated content.
            approx_string (str):
                Automatically generated string of the approximate ending time of the scan.

        -------------------
        Attributes for Tinkerforge and Steppermotor setup:

            HOST (str):
                "localhost"
            PORT (int):
                4223
            UIDSTEP1 (str):
                UID of Stepper Brick 1
            UIDSTEP2 (str):
                UID of Stepper Brick 2
                Since a core xy-setup is used, there is no such a x or y stepper.
            UIDSTEP3 (str):
                UID of Stepper Brick 3 (z-direction).
            UIDIO (str):
                UID of IO-16 Bricklet.
            UIDIDO4 (str):
                UID of IO-4 Bricklet.
            max_vel (int):
                Velocity of stepper 1 and 2.
            ramping (int):
                Ramping of stepper 1 und 2.
            z_max_vel (int):
                Velocity of z-steppers.
            z_ramping (int):
                Velocity of z-steppers.
            z_ramping (int):
                Ramping of z-steppers.

        -------------------
        Attributes used internally for the homing process:
            goto_queue = queue.Queue()
            spec_queue = queue.Queue()
            home_queue = queue.Queue()
            z_goto_queue = queue.Queue()
            s1_queue = queue.Queue()
            s2_queue = queue.Queue()
            measure_queue = queue.Queue()
            home_queue.put(None)
            home_queue.put(None)
            home_queue.put(None)
        
        -------------------
        Methods: See the respective function's docstring.
            connect()
            start_measurement()
            disconnect()

        Debugging methods for idle mode: (idle mode = connected and homed, no measurement running, mode=='idle')
            get_position()
            get_z_position()
            goto_position(position)
            tune_inttime()
            manual_homing()
            reset_queue()
    """
    def __init__(self,
                 reactor,
                 comment,
                 measurements,
                 power_supply,
                 averages=2,
                 x_start=0.0,
                 y_start=0.0,
                 voltage=5.,
                 current=0.7,
                 log_output=True,
                 linspace=False,  # for setting up the z spacing
                 slicelist=False,
                 int_time_linspace=False,
                 int_time_list=False,
                 sendmail=False
                 ):
        """
        Constructs all the necessary attributes for a ScanSurface instance.
        ------------------
        Parameters:

            reactor (str):
                The name of the experiment, will be used for output folder and files.

            comment (str):
                A comment for additional information, written to the logfile.

            measurements (int):
                The size of measurements of a quadratic canvas in x/y-direction. The points are evenly spaced by 3.9 mm.
                The maximum total size is 153 (59.67 cm).

            power_supply (bool):
                If True, the script controllers the power supply with the given parameters for voltage and current. If
                False, a dark spectrum for the chosen integration time must be provided in the format
                "dark_'integration time'_av'averages'.csv", whereas 'integration time'
                and 'averages' must be replaced with the respective numbers. The provided python script Dunkelspec.py
                can help with that.
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

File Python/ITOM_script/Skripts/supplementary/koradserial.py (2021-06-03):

""" Serial communication with Korad KA3xxxP power supplies.

The intent is to give easy access to the power supply as Python objects, eliminating the need to know
special codes.

The object supports the python `with` statement to release the serial port automatically:

from koradserial import KoradSerial

with KoradSerial('/dev/tty.usbmodemfd121') as device:
    print "Model: ", device.model
    print "Status: ", device.status

LICENSE: MIT

RESOURCES:

http://www.eevblog.com/forum/testgear/power-supply-ps3005d-ka3005d-rs232-protocol/
http://www.eevblog.com/forum/testgear/korad-ka3005p-io-commands/
http://sigrok.org/wiki/Velleman_PS3005D
https://gist.github.com/k-nowicki/5379272


"""




from enum import Enum
from time import sleep
import serial



__all__ = ['KoradSerial', 'ChannelMode', 'OnOffState', 'Tracking']


class ChannelMode(Enum):
    """ Represents channel modes.

    These values should correspond to the values returned by the ``STATUS?`` command.
    """
    constant_current = 0
    constant_voltage = 1


class OnOffState(Enum):
    """ Represents on/off states.

    This could just as easily be done as a Boolean, but is explicit.
    """
    off = 0
    on = 1


class Tracking(Enum):
    """ Tracking state for a multi-channel power supply.

    These values should correspond to the values returned by the ``STATUS?`` command.

    There seems to be conflicting information about these values.

    The other values I've seen are:
    *   0 - independent
    *   1 - series
    *   2 - parallel
    *   3 - symmetric

    However, I don't have a multi-channel power supply to test these.
    """
    independent = 0
    series = 1
    parallel = 3


class Status(object):
    """ Decode the KoradSerial status byte.

    It appears that the firmware is a little wonky here.

    SOURCE:

    Taken from http://www.eevblog.com/forum/testgear/korad-ka3005p-io-commands/

    Contents 8 bits in the following format
        Bit     Item        Description
        0       CH1         0=CC mode, 1=CV mode
        1       CH2         0=CC mode, 1=CV mode
        2, 3    Tracking    00=Independent, 01=Tracking series,11=Tracking parallel
        4       Beep        0=Off, 1=On
        5       Lock        0=Lock, 1=Unlock
        6       Output      0=Off, 1=On
        7       N/A         N/A
    """

    def __init__(self, status):
        """ Initialize object with a KoradSerial status character.

        :param status: Status value
        :type status: int
        """
        super(Status, self).__init__()
        self.raw = status
        self.channel1 = ChannelMode(status & 1)
        self.channel2 = ChannelMode((status >> 1) & 1)
        self.tracking = Tracking((status >> 2) & 3)
        self.beep = OnOffState((status >> 4) & 1)
        self.lock = OnOffState((status >> 5) & 1)
        self.output = OnOffState((status >> 6) & 1)

    def __repr__(self):
        return "{0}".format(self.raw)

    def __str__(self):
        return "Channel 1: {0}, Channel 2: {1}, Tracking: {2}, Beep: {3}, Lock: {4}, Output: {5}".format(
            self.channel1.name,
            self.channel2.name,
            self.tracking.name,
            self.beep.name,
            self.lock.name,
            self.output.name,
        )

    def __unicode__(self):
        return self.__str__()


def float_or_none(value):
    try:
        return float(value)
    except (TypeError, ValueError):
        return None


class KoradSerial(object):
    """ Wrapper for communicating with a programmable KoradSerial KA3xxxxP power supply as a serial interface.
    """

    class Channel(object):
        """ Wrap a channel. """

        def __init__(self, serial_, channel_number):
            """

            :type serial_: KoradSerial.Serial
            :type channel_number: int
            """
            super(KoradSerial.Channel, self).__init__()
            self.__serial = serial_
            self.number = channel_number

        @property
        def current(self):
            result = self.__serial.send_receive("ISET{0}?".format(self.number), fixed_length=6)
            # There's a bug that return a 6th character of previous output.
            # This has to be read and discarded otherwise it will be prepended to the next output
            #return float_or_none(result[:5])

        @current.setter
        def current(self, value):
            self.__serial.send("ISET{0}:{1:05.3f}".format(self.number, value))

        @property
        def voltage(self):
            return float_or_none(self.__serial.send_receive("VSET{0}?".format(self.number), fixed_length=5))

        @voltage.setter
        def voltage(self, value):
            self.__serial.send("VSET{0}:{1:05.2f}".format(self.number, value))

        @property
        def output_current(self):
            """ Retrieve this channel's current current output.

            :return: Amperes
            :rtype: float or None
            """
            result = self.__serial.send_receive("IOUT{0}?".format(self.number), fixed_length=5)
            return float_or_none(result)

        @property
        def output_voltage(self):
            """ Retrieve this channel's current current voltage.

            :return: Volts
            :rtype: float or None
            """
            result = self.__serial.send_receive("VOUT{0}?".format(self.number), fixed_length=5)
            return float_or_none(result)

    class Memory(object):
        """ Wrap a memory setting. """

        def __init__(self, serial_, memory_number):
            super(KoradSerial.Memory, self).__init__()
            self.__serial = serial_
            self.number = memory_number

        def recall(self):
            """ Recall this memory's settings.  """
            self.__serial.send("RCL{0}".format(self.number))

        def save(self):
            """ Save the current voltage and current to this memory. """
            self.__serial.send("SAV{0}".format(self.number))

    class OnOffButton(object):
        """ Wrap an off/off button. """

        def __init__(self, serial_, on_command, off_command):
            super(KoradSerial.OnOffButton, self).__init__()
            self.__serial = serial_
            self._on = on_command
            self._off = off_command

        def on(self):
            self.__serial.send(self._on)

        def off(self):
            self.__serial.send(self._off)

    class Serial(object):
        """ Serial operations.

        There are some quirky things in communication. They go here.
        """

        def __init__(self, port, debug=False):
            super(KoradSerial.Serial, self).__init__()

            self.debug = debug
            self.port = serial.Serial(port, 9600, timeout=1)
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

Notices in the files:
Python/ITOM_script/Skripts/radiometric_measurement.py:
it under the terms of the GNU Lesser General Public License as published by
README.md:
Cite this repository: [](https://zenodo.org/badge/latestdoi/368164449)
